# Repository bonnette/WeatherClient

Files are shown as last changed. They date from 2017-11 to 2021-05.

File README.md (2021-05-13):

# WeatherClient
Is an ESP8266 with OLED display designed to connect to a Switchdoc Labs WeatherPlus board and display weather data to the user over wifi.

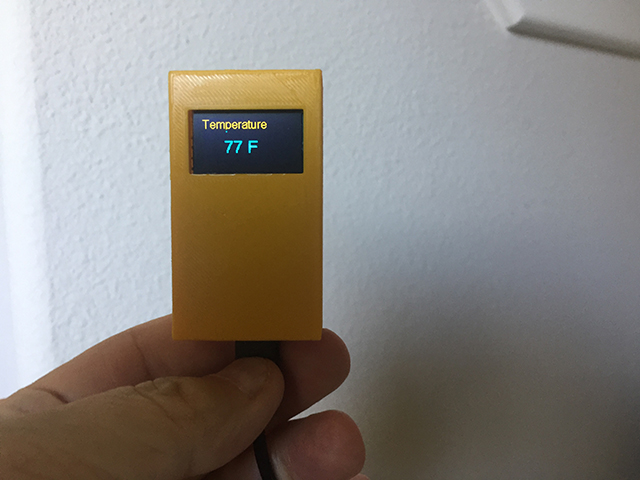
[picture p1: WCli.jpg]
Client Photo


The purpose of each file is:

-  WCi.jpg is a photo of the completed unit.
-  HomeClient.ino is used on a WeatherPi and should **not** be used to "talk" to the WeatherPlus board
- .FCStd files are "FreeCad" source files
- .cdr file is a CorelDraw file with dimensions of the unit
- .ino files are two different versions of the units code (see wiki)
- .png file is a wireing diagram.
- .stl files are 3D printer files.
- .fzz file is a Fritzing file

More information can be found in the wiki.

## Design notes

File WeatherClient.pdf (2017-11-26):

Switchdoc.com provides a nice little Weather board that is based on an ESP8266 Arduino.

The board, called “WeatherPlus” is an all in one weather station controller.

The controller can be bought separately or can be purchased in a larger kit called the “OurWeather”

OurWeather is a connected weather station containing 7 different sensors including Wind speed, Direction, Rain Gauge etc.

If you buy the “WeatherPlus” board as part of the “OurWeather” format. It comes with a little 1-inch OLED display that can be set to continuously display the weather information extracted from the “WeatherPlus” weather controller.

This works well. But, the display is connected (physically) to the “WeatherPlus” board. And, the “WeatherPlus” board is typically sitting outside of the house near the weather sensors.

Wouldn’t it be nice if that display were a wireless display that could be placed anywhere in the home ?

That is what this project is all about.

The device (Pictured below) called the “WeatherClient” uses just two components.

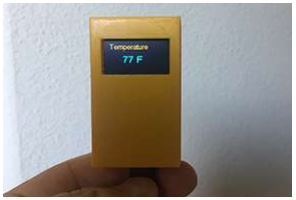
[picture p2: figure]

A NodeMCU V3 board (or similar). We will call this the CPU board. https://www.amazon.com/gp/product/B071YPS666/ref=oh_aui_detailpage_o01_s00?ie=UTF8&psc=1

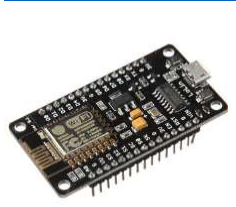
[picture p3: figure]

and a 1-inch OLED display. We will call this the client display. https://www.amazon.com/gp/product/B01HEBIJKK/ref=oh_aui_detailpage_o08_s00?ie=UTF8&psc=1

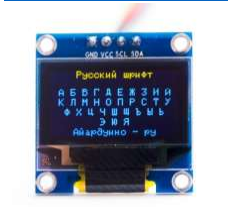
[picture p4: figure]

You can power the project using a USB cable connected to your computer or you can get a wall wart. https://www.amazon.com/gp/product/B00MARDJZ4/ref=oh_aui_detailpage_o06_s00?ie=UTF8&psc=1

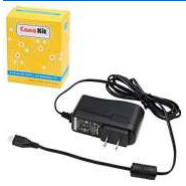
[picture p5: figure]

The CPU board uses an ESP8266 as the Wi-Fi connection. This will allow us to “talk” to the weather board over your local wireless network.

The code for the Weather Client makes a connection to your local Wi-Fi and then queries your WeatherPlus board (using the wireless network). The code then extracts Time, Temperature, Humidity and wind speed and displays it on the Weather Client display.

Because you are using the local wireless to get the data from the WeatherPlus board. You can place the Weather Client almost anywhere in the house.

I provide the “STL” files to enable you to 3D print a small case and cover.

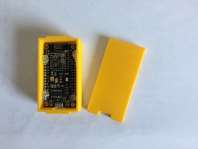
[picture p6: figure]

All necessary information for building the Weather Client can be obtained from: https://www.thingiverse.com/thing:2527547

The whole project should cost you less than $30
OLED = $9
CPU = $7
Wall Wart = $10

The WeatherClient is wired in this manner:

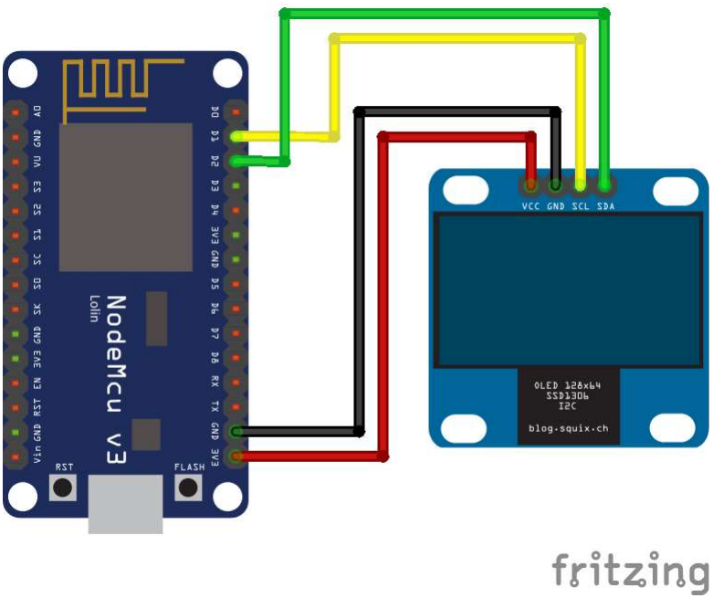
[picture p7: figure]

The code is in a file called WeatherClient.ino and will require you to modify:

Line 84
const char* host = "192.168.0.220"; // WeatherPlus board address Change the above line and enter your WeatherPlus board IP address.

Line 114 and 115
WiFi.begin("Your Wireless SSID", "Your Wireless Password"); WiFi.config(IPAddress(192,168,0,219), IPAddress(192,168,0,1), IPAddress(255,255,255,0)); Change the above two lines. Enter your Wi-Fi information and your Weather Clients IP address, Gateway and subnet mask.

The library used for the OLED display is from https://github.com/squix78/esp8266-oled-ssd1306 The Adafruit driver did not seem to work for some reason.
The following is the OLED library used in this project:
#include "SSD1306.h" // alias for `#include "SSD1306Wire.h"`

A word about the information above.
Line 84 (in the WeatherClient.ino file) is the WeatherPlus (not the WeatherClient) ip address. You can get this address off of the OLED display connected to the WeatherPlus board when the WeatherPlus board first boots up.

If you would like to guarantee that the WeatherPlus board ALWAYS boots up with the same address (and this is what I do). Download the latest WeatherPlus code from github. https://github.com/switchdoclabs/OurWeatherWeatherPlus
Load the code into the Arduino IDE and assign an address to the Weather plus board like this:

In the SDL_ESP8266_WeatherPlus.ino file add the following line (around line 656) just above the line that says //reset saved settings

wifiManager.setSTAStaticIPConfig(IPAddress(192,168,1,77), IPAddress(192,168,1,1), IPAddress(255,255,255,0));
//reset saved settings

Replace the addresses with your new assigned address, gateway and subnet mask.
In the example above the new IP address is 192.168.1.77 and the gateway is 192.168.1.1 the subnet mask is (almost) always 255.255.255.0
This will force the WeatherPlus to use this new address.
One other note. Notice that the addresses above are separated with comas “,” and not periods “.”

If you are not sure about how addresses are assigned or derived please ask someone with networking experience to help.

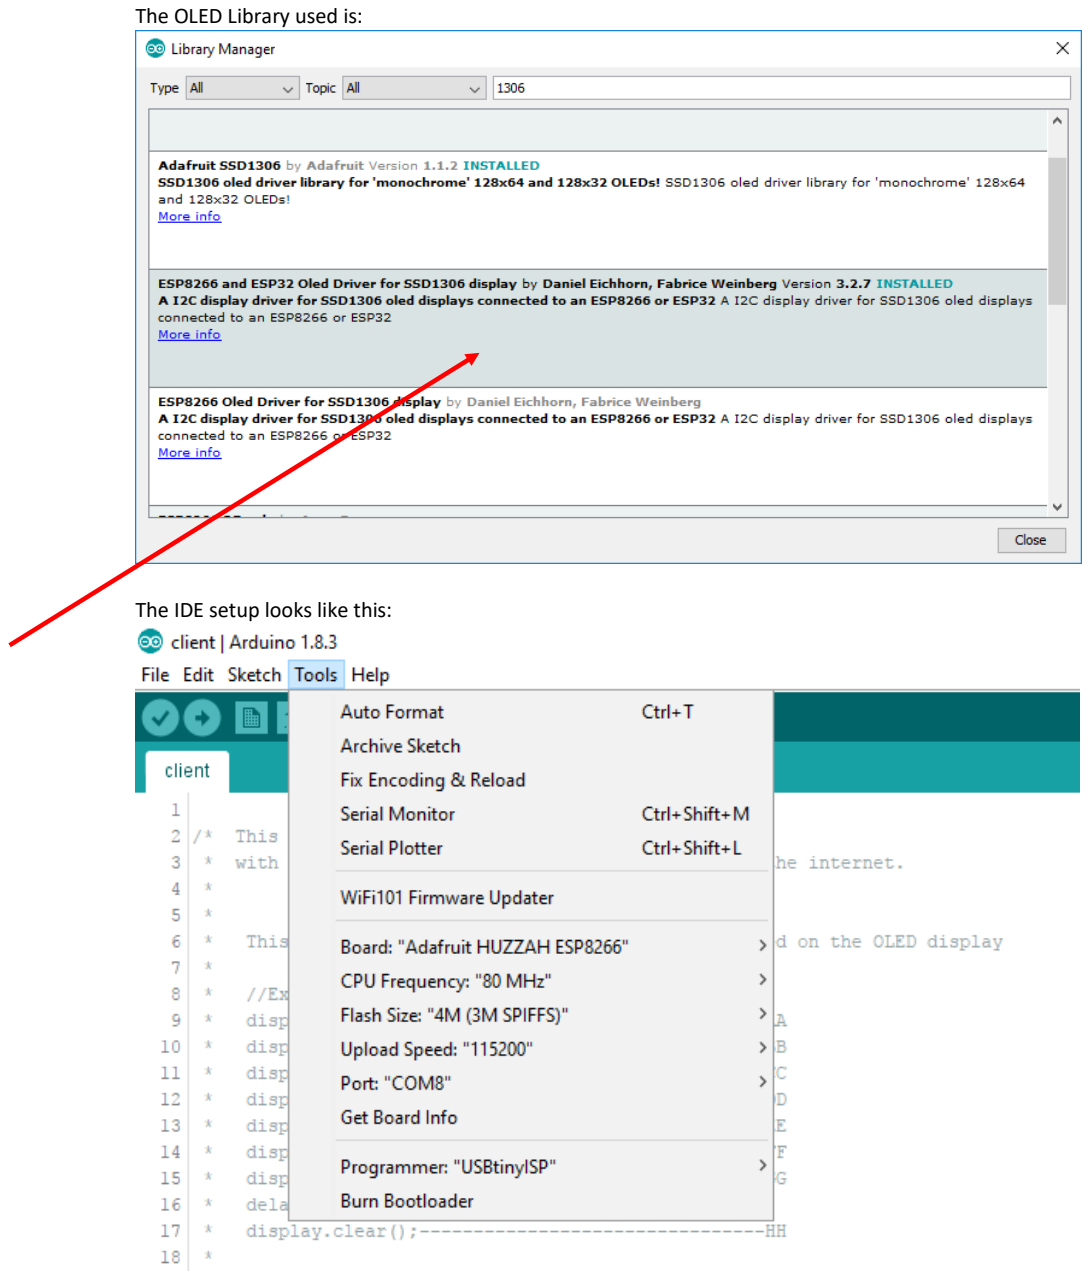
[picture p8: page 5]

The OLED Library used is:

The IDE setup looks like this:

Assembling the box
If your OLED has a connector on it. Remove the connector. Then wire up the OLED to the CPU board.

I use hot glue to fasten all of the components into the case. Why ?
Because hot glue is easy to remove if you need to make repairs.

After wiring up the unit, use hot glue to fasten the OLED display into the box.

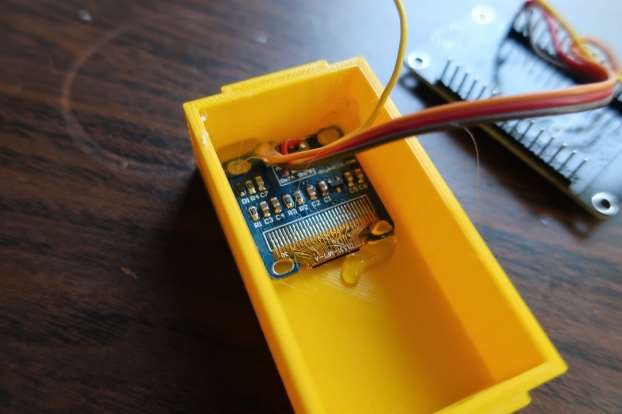
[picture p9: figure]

Don’t use too much glue and try to keep it away from the right and left side of the box because the pins on the CPU need to sit straddling the OLED display.

Next place the CPU board into the box and use hot glue to fasten it into the box. Be sure that the CPU boards pins are straddling the display and that the pins are sitting flush against the case.

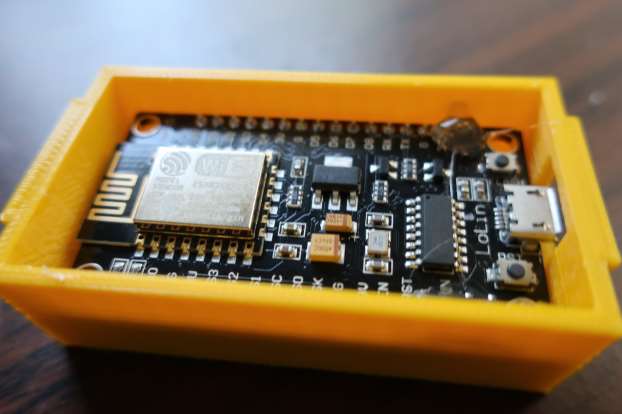
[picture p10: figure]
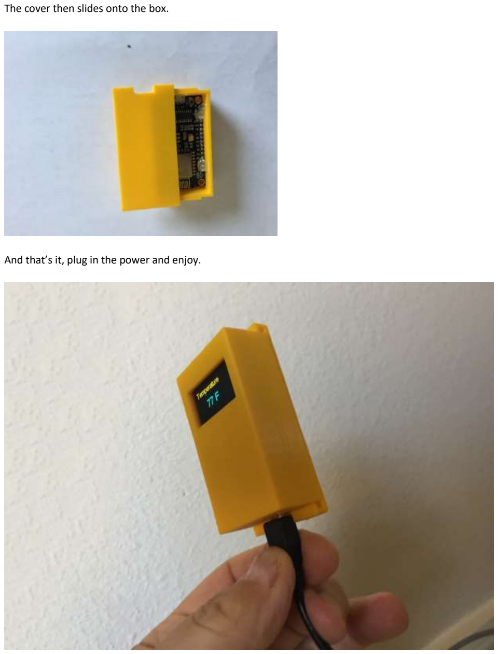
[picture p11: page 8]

The cover then slides onto the box.

And that’s it, plug in the power and enjoy.

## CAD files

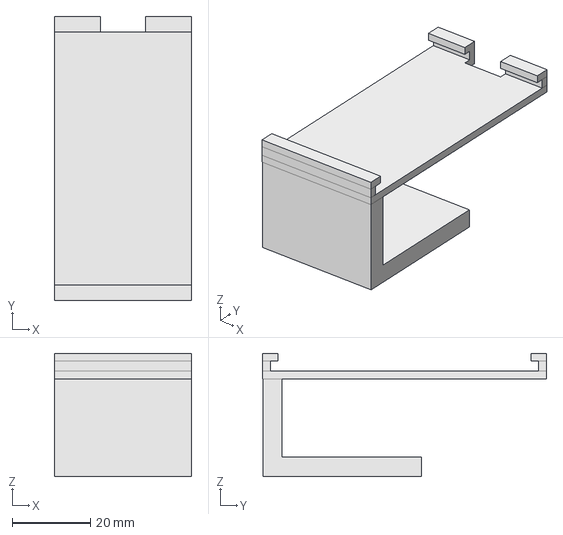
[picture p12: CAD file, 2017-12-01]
WeatherClient_tophook.FCStd
35.0 x 72.5 x 31.5 mm

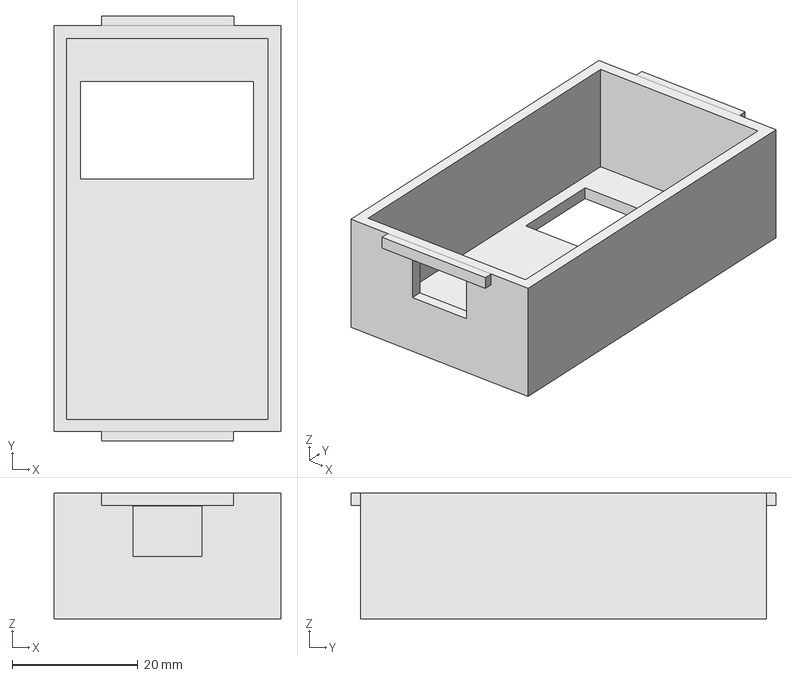
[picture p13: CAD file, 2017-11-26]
WeatherClient.FCStd
36.0 x 67.5 x 20.0 mm

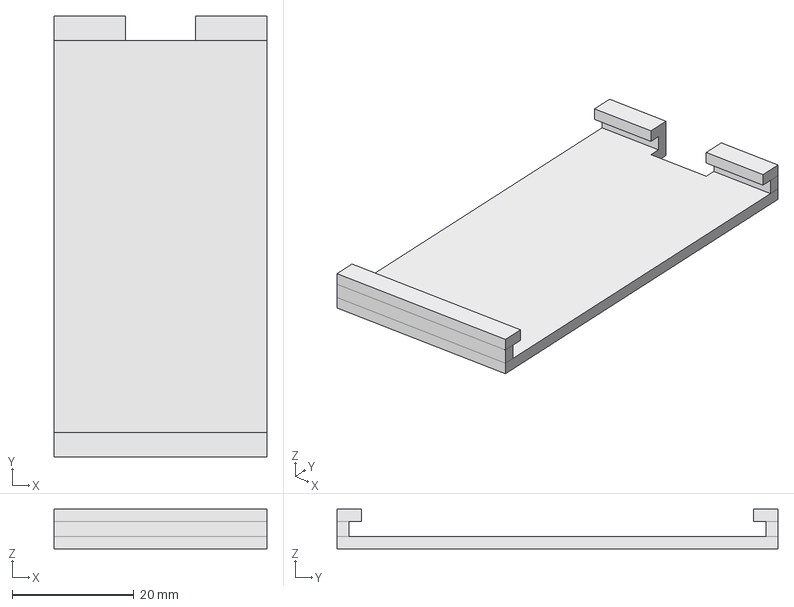
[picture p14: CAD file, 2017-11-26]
WeatherClient_top.FCStd
35.0 x 72.5 x 6.50 mm

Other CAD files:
WeatherClient.stl
WeatherClient_top.stl
WeatherClient_topHook.stl

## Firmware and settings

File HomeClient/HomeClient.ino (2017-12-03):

/*  This code was written by Larry Bonnette.
 *  with help from code gleaned from many sources on the internet.
 *   
 *   
 *   This section explains how charaters are positioned on the OLED display
 *   This is the code used to display text on the OLED
 *   
 *   //Example Display on OLED for "Current Time"
 *   display.setTextAlignment(TEXT_ALIGN_LEFT);------AA
 *   display.setFont(ArialMT_Plain_16);--------------BB
 *   display.drawString(0,0,"Current Time");---------CC
 *   display.setFont(ArialMT_Plain_16);--------------DD
 *   display.drawString(15,20,ODtimd);---------------EE
 *   display.drawString(15,40,ODtimt);---------------FF
 *   display.display();------------------------------GG
 *   delay(5000);
 *   display.clear();--------------------------------HH
 *   
 *   AA Sets up the alignment IE left to right in the example
 *   BB Sets the font and the size of font available font is 10,16 and 24 (Other fonts can be added to the .h file) the font is set to Arial 16
 *   CC Puts a string in the OLED buffer. In the example, "Current Time" is the string and is positioned in the first pixel on the first line 
 *      (0,0,"String") the first "0" is the first pixel. The second "0" is how many pixels down. So, "Current Time" shows up in the upper left hand corner.
 *   DD Changes the font. In the example, the font stays the same at "16". It is in the code to remind me that fonts can be changed at anytime.
 *   EE Puts a string in the OLED buffer. In this case, the date retrieved from the weather station is placed at the 15th pixel from the left of the screen and 20 pixels down.
 *   FF Puts a string in the OLED buffer. In this case, the time retrieved from the weather station is placed at the 15th pixel from the left of the screen and 40 pixels down.
 *   GG Tells the OLED to display the data in the buffer onto the OLED screen.
 *   HH Clears the screen
 *   
 *  ********************************************************************************************************************************* 
 *   This section explains how data is extracted from information sent from the WeatherPi.
 *   
 *   Data from the WeatherPi looks like this:
 *   
 *   {"FullDataString": "25.10,51.30,0.00,0.00,0.00,0.00,0.00,0.00,0.00,0.00,0.00,0.00,0.00,0.00,0.00,0,09/10/2017 10:16:20,,0,-1,0.00,0.00,0.00,0.00,0.00,0.00,0.00,0.00,0.00,0.00,0.00,0.00,V:1,WXLMB ,", , "id": "1", "name": "OurWeather", 
 *   "connected": true}<--------------------------------------This is the final charater sent from the WeatherPi.
 *    
 *   This is the code used to extract components like "Temperature" and "Wind Speed" etc. The example
 *   below extracts the time and date.
 *    
 *   // Extract and display the current time from the recieved data
 *   String line = client.readStringUntil('EOF');----------------------------------------AA
 *   int tim = hold;---------------------------------------------------------------------BB
 *   String ODtimd = line.substring(tim - 20,tim - 9);-----------------------------------CC
 *   String ODtimt = line.substring(tim - 9,tim + 1);------------------------------------DD
 *   Serial.println("The Date is: " + ODtimd);-------------------------------------------EE
 *   Serial.println("The Time is: " + ODtimt);-------------------------------------------FF
 *   
 *   AA reads the data comming from the WeatherPi using the function call "client.readStringUntil". The function reads all of the text
 *      comming from the WeatherPi and places it into a variable "line" until it gets to a "EOF" charater. At this charater the function stops reading. 
 *      Now, "line" contains all of the data drom the WeatherPi (as shown above). 
 *   BB Now we will get the "time" infromation from the data inside "line". This is done by counting the commas in the variable "line" and getting an index number that represents the position
 *      in the data of the "time data"( the 17th comma, see code below) We save that index number into a variable called "tim"
 *   CC Now that we have a number that represents the position of the "time data". (look at the example above) you can see that if you count charaters starting 
 *      from zero at {"FullDataString" that the time data starts just after the 17th comma. So, we start saving data from "tim - 20" to "tim - 9" into a variable "ODtimd"
 *      "ODtimd" now contains the date extracted from the data sent from the WeatherPi.
 *   DD We do the same as above to get the "time". The time starts a "tim - 9" until "tim + 1". We store the time in "ODtimt"
 *   EE Prints the date onto the serial monitor
 *   FF Prints the time onto the serial monitor.
 *   
 *   The OLED example (at the top of the page) uses the ODtimd and ODtimt variables and displays them on the OLED
 *   
 * ******************************************************************************************************************************************
 */
    
//------------------------------------------------------------------------------------
// Libraries Needed For This Project
//------------------------------------------------------------------------------------
  #include <Wire.h>           // To Be Able To Use Sensors Like IMU9050
  #include <EEPROM.h>         // To Be Able To Store & Read Data Between Power Off
  #include <ESP8266WiFi.h>    // The Basic Function Of The ESP NOD MCU
  #include "SSD1306.h" // alias for `#include "SSD1306Wire.h"`
//  #include "SH1106.h" alis for `#include "SH1106Wire.h"`
// Initialize the OLED display using Wire library (I2C address, Data pin, Clock pin)
    SSD1306  display(0x3c, 4, 5);
//    SH1106 display(0x3c, 4, 5);
//------------------------------------------------------------------------------------
// WIFI Module Role & Port
//------------------------------------------------------------------------------------
// This WIFI Module Code Works As A Client that Will Connect To A WeatherPi (Web server) With an TCP/IP address of 192.168.0.196

  int ServerPort  = 80;
  //const char* host = "192.168.1.77"; // WeatherPi address
  const char* host = "192.168.0.196"; // WeatherPi address
  
  WiFiClient      client; //initiate Wi-Fi client as "client"
//====================================================================================

  void setup() 
  {

  // Initialising the UI will init the display too.
  display.init();

  display.flipScreenVertically();
  display.setFont(ArialMT_Plain_10);

    // Setting The Serial Port ----------------------------------------------
    delay(1000);
    Serial.begin(115200);           // Serial port set to 115200 baud
    Serial.println("Begin initialization of WeatherClient");

    // Starting To Connect --------------------------------------------------
    if(WiFi.status() == WL_CONNECTED)
    {
      WiFi.disconnect();
      WiFi.mode(WIFI_OFF);
      delay(50);
    }

    // The WeatherClient loads the ssid and password for the wireless connection
    
    WiFi.mode(WIFI_STA);            // To Avoid Broadcasting An SSID

    WiFi.begin("Your SSID", "Your WiFi password");      // The wireless SSID That We Want To Connect to and a password
    WiFi.config(IPAddress(192,168,0,221), IPAddress(192,168,0,1), IPAddress(255,255,255,0)); //Define a static client ip address (not using DHCP)


    // Printing Message for the user that a connetion is in progress
    Serial.println("**** Connecting To " + WiFi.SSID() + " ****");
    
    // OLED display connection details
    display.setTextAlignment(TEXT_ALIGN_LEFT);
    display.setFont(ArialMT_Plain_16);
    display.drawString(0,0,"Connecting To");
    display.setFont(ArialMT_Plain_10);
    display.drawString(0, 25,WiFi.SSID());
    display.display();
    delay(5000);


    Serial.println("**** WeatherClient Connected ****");

    // Printing IP Address --------------------------------------------------
    Serial.println("Connected To      : " + String(WiFi.SSID()));
    Serial.println("Signal Strenght   : " + String(WiFi.RSSI()) + " dBm");
    Serial.print  ("Server IP Address : ");
    Serial.println(host);
    Serial.print  ("Server Port Num   : ");
    Serial.println(ServerPort);
    // Printing MAC Address
    Serial.print  ("Device MC Address : ");
    Serial.println(String(WiFi.macAddress()));
    // Printing IP Address
    Serial.print  ("Device IP Address : ");
    Serial.println(WiFi.localIP());

  }
    


//====================================================================================
  
  void loop()
  {
  // clear the display
  display.clear();
  delay(1000); //Wait 1 Seconds 
  Serial.println("In Loop");

// Make a connection to the weather server
   if (client.connect(host, ServerPort)) {

// Send a query for weather information

  client.print("GET /wthrdata.dat \r\n Connection: close \r\n");

  }
  else {
    Serial.println("Connection Failed");
    // OLED display connection details
    display.setTextAlignment(TEXT_ALIGN_LEFT);
    display.setFont(ArialMT_Plain_16);
    display.drawString(0,0,"Connection Fail");
    display.setFont(ArialMT_Plain_10);
    display.drawString(0, 25,"Retrying Connection");
    display.display();
    delay(5000); // If connection to server failed give it a few seconds
    display.clear();
  }
// If connection succeded then read the weather information into a buffer. (called line)
while (client.connected())
{
  if (client.available())
  {
    String line = client.readStringUntil(EOF); // the last charater in the data is a "EOF" so stop reading when we get this.
    Serial.println(line); // for testing this will print everything
    
// Display Information on ther serial terminal
// Extract and display the current time from the recieved data
// The following code counts commas. 
    int hold = 0;
    // Get time (17th comma)
    hold = GetComma(17, line);          // Place the index number into "hold"

    int tim = hold;                                    // the index number of the 17th commas is used to get the time.
    //Serial.println(tim);
    String ODtimd = line.substring(tim - 20,tim - 9); // The 17th comma is at the end of the "Date/Time" string. So we back up 20 charaters and extract the date
    String ODtimt = line.substring(tim - 9,tim - 1); // The 17th comma is at the end of the "Date/Time" string. So we back up 9 charaters to extract the time.
    Serial.println("The Date is: " + ODtimd); //Display the date
    Serial.println("The Time is: " + ODtimt); //Display the time

// Extract and display the current outdoor temperature.
    int temp = line.indexOf(String(","));            // The Outdoor temperature is at the very first comma so we set the index to there.
    String ODtemp = line.substring(temp - 4,temp );  //The 1st comma is at the end of the "Outdoor Temp" string. So we back up 4 charaters to extract the temp.
    //Serial.println(ODtemp);
    int tempint = ODtemp.toInt();                   // convert to int so we can convert "C" to Faranheight 
    //Serial.println(String(tempint));
    tempint = (tempint*1.8)+32;   // convert "C" to "F"
    ODtemp = String(tempint);
    Serial.println("Temp in C = " + ODtemp);
    Serial.println("The Outdoor Temp is: " + ODtemp); // Display the temp in "F"


// Extract and display the current outdoor humidity.
    int humi = line.indexOf(String(","), temp + 1); // The Humidity is at the first comma after the Outdoor temp, so we set the index to there.
    String ODhumi = line.substring(humi - 4, humi); // The second  comma is at the end of the "Humidity" string. So we back up 4 charaters to extract the humidity.
    Serial.println("The Outdoor Humidity is: " + ODhumi); // Display  the Humidity

// Extract and display the current indoor temperature.
    int tempi = line.indexOf(String(","), humi + 1); // Search for indoor Temp
    String IDtemp = line.substring(tempi - 4,tempi); // when found extract the indoor Temp
    int idtempint = IDtemp.toInt(); // convert to int so we can convert "C" to Faranheight 
    idtempint = (idtempint*1.8)+32; // convert "C" to "F"
    IDtemp = String(idtempint);
    Serial.println("Temp in C = " + IDtemp);
    Serial.println("The Indoor Temperature is: " + IDtemp); // Display  the indoor Temp

// Extract and display the current barometric pressure.
    int prsur = line.indexOf(String(","), tempi + 1); // Search for pressure
    String IDpress = line.substring(prsur - 8,prsur); // when found extract the pressure
    float pressint = IDpress.toInt(); // convert to int so we can convert to inch mercury 
    pressint = (pressint/33.863)/100; // convert hga to inches mercury
    Serial.println("The Barometric Pressure is: " + IDpress); // Display  the pressure in hGa
    Serial.println("The Barometric Pressure is: " + String(pressint)); // Display  the pressure in inches of mercury

// Extract and display the current wind speed
    // Get wind speed (5th comma)
    hold = GetComma(5, line);
    int wspeed = hold; //place index number into wind speed
    // Get wind Direction (7th comma)   
    hold = GetComma(7, line);     
    int wdir = hold; //place index number into wind speed
    String ODspeed = line.substring(wspeed - 4,wspeed); // when found extract the Wind Speed
    int ODspeedint = ODspeed.toInt();
    ODspeedint = ODspeedint * 0.62137119223733;
    ODspeed = String(ODspeedint);
    String ODdir = line.substring(wdir - 5,wdir); // when found extract the Wind direction
    String NUMdir = ODdir;
    int INTdir = ODdir.toInt();
    ODdir = getWdir(INTdir);
    Serial.println("The Wind Speed is: " + ODspeed + " MPH"); // Display  the Wind Speed
    Serial.println("Direction number: " + NUMdir);
    Serial.println("The Wind Direction is: " + ODdir); // Display  the Wind Direction
    
    client.stop(); // disconnect from server so we don't keep displaying the info.

//    int t = 5;     // This is used to decrease the number of times the client asks for weather info
//    while(t>0){   // Display information on OLED 5 (1 minute 15 seconds) times before getting data from WeatherPi again. 
    
    //Display on OLED current Time
    display.setTextAlignment(TEXT_ALIGN_LEFT);
    display.setFont(ArialMT_Plain_16);
    display.drawString(0,0,"Current Time");
    display.setFont(ArialMT_Plain_16);
    display.drawString(15,20,ODtimd); // print out the date
    display.drawString(15,40,ODtimt); // print out the time
    display.display();
    delay(5000);
    display.clear();
    
    // Display on OLED Temperature   
    display.setTextAlignment(TEXT_ALIGN_LEFT);
    display.setFont(ArialMT_Plain_16);
    display.drawString(0,0,"Outdoor Temp");
    display.setFont(ArialMT_Plain_24);
    display.drawString(30, 25,String(tempint) + " F");
    display.display();
    delay(5000);
    display.clear();
    
    // Display on OLED Humidity   
    display.setTextAlignment(TEXT_ALIGN_LEFT);
    display.setFont(ArialMT_Plain_16);
    display.drawString(0,0,"Humidity");
    display.setFont(ArialMT_Plain_24);
    display.drawString(15,25,ODhumi + " %");
    display.display();
    delay(5000);
    display.clear();

    // Display on OLED indoor Temperature   
    display.setTextAlignment(TEXT_ALIGN_LEFT);
    display.setFont(ArialMT_Plain_16);
    display.drawString(0,0,"In-Box Temp");
    display.setFont(ArialMT_Plain_24);
    display.drawString(30, 25,String(idtempint) + " F");
    display.display();
    delay(5000);
    display.clear();

    // Display on OLED Barometric Pressure   
    display.setTextAlignment(TEXT_ALIGN_LEFT);
    display.setFont(ArialMT_Plain_16);
    display.drawString(0,0,"Pressure");
    display.setFont(ArialMT_Plain_24);
    display.drawString(30, 25,String(pressint) + " ");
    display.display();
    delay(5000);
    display.clear();

    // Display on OLED Wind Speed   
    display.setTextAlignment(TEXT_ALIGN_LEFT);
    display.setFont(ArialMT_Plain_16);
    display.drawString(0,0,"Wind");
    display.setFont(ArialMT_Plain_16);
    display.drawString(0,15,ODdir);
    display.setFont(ArialMT_Plain_24);
    display.drawString(15,35,ODspeed + " MPH");
    display.display();
    delay(5000);
    display.clear();
//    --t;
//    }
  }
}
//delay(30000); // Wait 30 seconds and do it all again
  }

//====================================================================================
// Routine to convert Wind direction from numbers to text (returns text)
//====================================================================================
  String getWdir(int zz)
  {
    if(zz >= 0  && zz < 22) {
        return("North");}
        
        else if (zz >= 22  && zz < 45) {
        return("North North East");}
        
        else if (zz >= 45  && zz < 67) {
        return("North East");}

        else if (zz >= 67  && zz < 90) {
        return("East North East");}

        else if (zz >= 90 && zz < 112)  {
        return("East");}

        else if (zz >= 112 && zz < 135)  {
        return("East South East");}

        else if (zz >= 135 && zz < 157)  {
        return("South East");}

        else if (zz >= 157 && zz < 180)  {
        return("South South East");}

        else if (zz >= 180 && zz < 202)  {
        return("South");}

        else if (zz >= 202 && zz < 225)  {
        return("South South West");}

        else if (zz >= 225 && zz < 247)  {
        return("South West");}

        else if (zz >= 247 && zz < 270)  {
        return("West South West");}

        else if (zz >= 270 && zz < 292)  {
        return("West");}

        else if (zz >= 292 && zz < 315)  {
        return("West North West");}

        else if (zz >= 315 && zz < 337)  {
        return("North West");}

        else if (zz >= 337 && zz < 359)  {
        return("North North West");}
        return("Unknown");
    }

//=======================================================================================================================================
// Routine to extract an index number for the position of the nth comma in "wthrdata.dat" x= number of commas to the data y= wthrdata.dat
// The number of commas (x) is passed to this routine. The text with the commas in it (y) is passed to this routine.
// The index number (the number of charaters counted to the nth comma) is returned (rtnval)
//=======================================================================================================================================
    int GetComma(int x, String y)
    {
    int rtnval = 0;
    int nxtcmma = 0;
    for (int cmmas = 0; cmmas < x; cmmas++) {              // Set the number of commas to find (17 is where the time is stored in "wthrdata.dat")
      if (cmmas == 0) {rtnval = y.indexOf(String(","));}   // The first time through we set the index number of the very first comma into "rtnval"
      nxtcmma = y.indexOf(String(","), rtnval +1);         // we then find the second comma and store the index number into "nxtcmma"
      nxtcmma = nxtcmma - rtnval;                          // We adjust the "nxtcmma" to reflect the difference between the last comma found and the "rtnval" comma
      rtnval = rtnval + nxtcmma;                           // We add the difference number plus the last "rtnval" number and store it in "rtnval"
      //Serial.println(hold);    
  }
      return(rtnval);                                      // We return the number of charaters counted (which gives us the position of the data needed)
      }

//====================================================================================
